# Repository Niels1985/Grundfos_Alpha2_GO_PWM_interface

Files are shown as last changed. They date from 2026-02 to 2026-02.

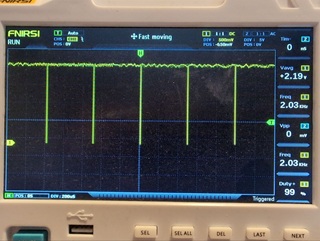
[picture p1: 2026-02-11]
foto2.jpg

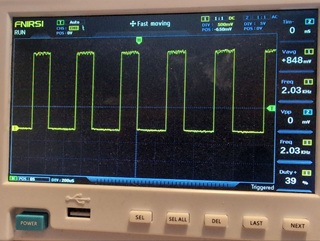
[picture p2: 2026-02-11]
foto1.jpg

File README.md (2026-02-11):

# Grundfos_Alpha2_GO_PWM_interface
Arduino IDE sketch for ATtiny85 microcontroller. When pin 7 (PB2) is high a PWM from 11% tot 84% is on pin 6 (PB1). Pin 3 (PB4) is analog in for potentiometer to set the PWM from 11% to 84%. When digital in is off then 97% PWM is send. (97% = pump off)(11% to 84% = pump minimum rpm to pum maximum rpm).

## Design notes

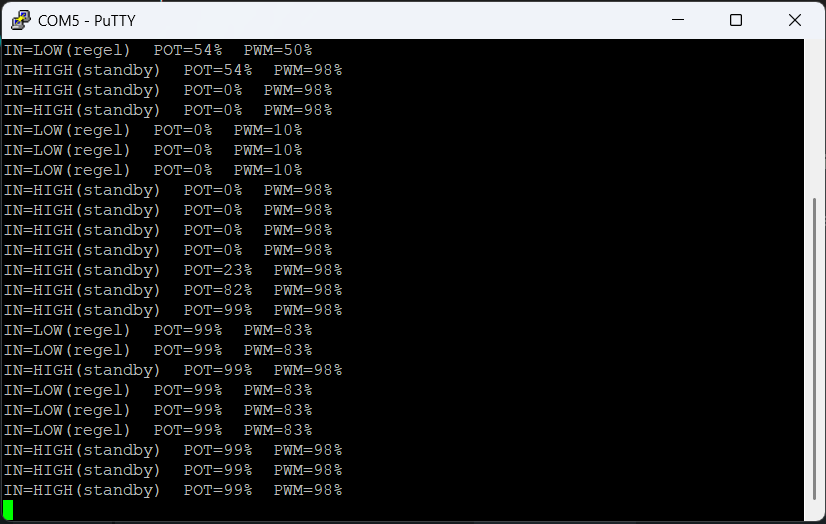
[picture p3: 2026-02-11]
serial_monitor.png

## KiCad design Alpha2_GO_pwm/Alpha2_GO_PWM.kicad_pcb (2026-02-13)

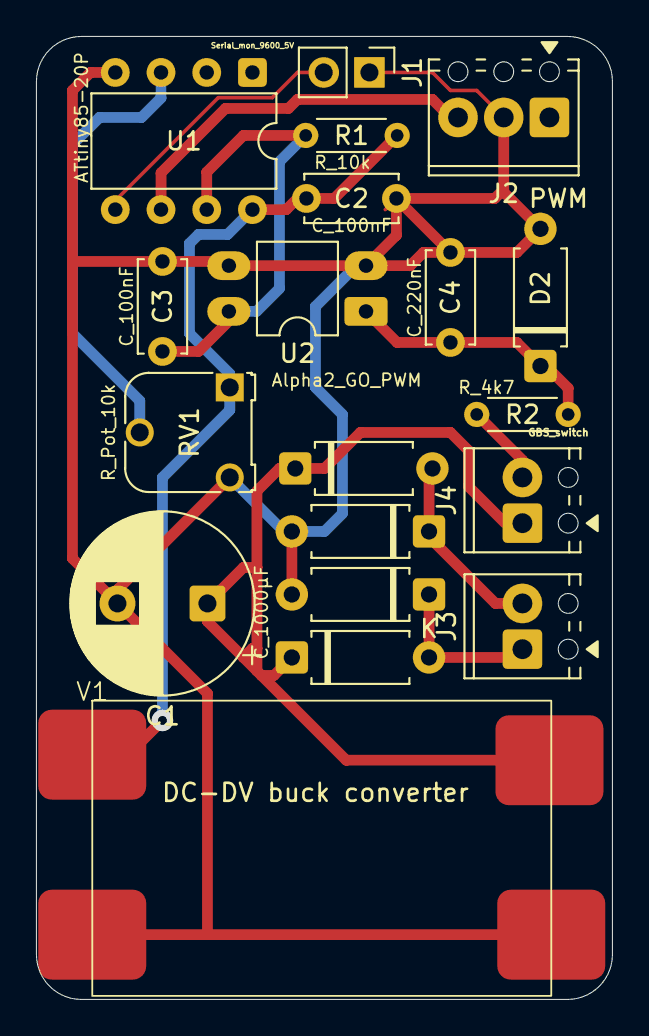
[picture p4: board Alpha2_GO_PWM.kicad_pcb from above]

Board: 2 copper layers, 32.0 x 53.5 mm, 19 parts (0 on the bottom side), 11 nets.

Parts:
C1: C_1000µF; CP_Radial_D10.0mm_P5.00mm
C2, C3: C_100nF; C_Disc_D5.0mm_W2.5mm_P5.00mm
C4: C_220nF; C_Disc_D5.0mm_W2.5mm_P5.00mm
D2: D_1N4148; D_A-405_P7.62mm_Horizontal
D3, D4, D5, D6: D; D_A-405_P7.62mm_Horizontal
J1: Serial_mon_9600_5V; PinHeader_1x02_P2.54mm_Vertical
J2: PWM; TerminalBlock_Phoenix_MPT-0,5-3-2.54_1x03_P2.54mm_Horizontal
J3: Suply 24V~; TerminalBlock_Phoenix_MPT-0,5-2-2.54_1x02_P2.54mm_Horizontal
J4: GBS_switch; TerminalBlock_Phoenix_MPT-0,5-2-2.54_1x02_P2.54mm_Horizontal
R1: R_10k; R_Axial_DIN0204_L3.6mm_D1.6mm_P5.08mm_Horizontal
R2: R_4k7; R_Axial_DIN0204_L3.6mm_D1.6mm_P5.08mm_Horizontal
RV1: R_Pot_10k; Potentiometer_Runtron_RM-065_Vertical
U1: ATtiny85-20P; DIP-8_W7.62mm
U2: Optocoupler_DC_PhotoNPN_AKEC; DIP-4_W7.62mm_LongPads
V1: V100EY9

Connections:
+5V: C2.2, R1.1, RV1.1, U1.8 (VCC), V1.4 (Vout-)
+24V: C1.1, D3.1 (K), D4.1 (K), J4.1, V1.1 (Vin+)
GND: C1.2, C2.1, C3.1, C4.1, D2.2 (A), D5.2 (A), D6.2 (A), J1.1, J2.2, RV1.3, U1.4 (GND), U2.2, U2.3, V1.2 (Vin-), V1.3 (Vout+)
unnamed: C4.2, D2.1 (K), R2.2, U2.1
unnamed: D3.2 (A), D5.1 (K), J3.2
unnamed: D4.2 (A), D6.1 (K), J3.1
unnamed: J1.2, U1.5 (AREF/PB0)
unnamed: J2.3, U1.6 (PB1)
unnamed: J4.2, R2.1
unnamed: C3.2, R1.2, U1.7 (PB2), U2.4
unnamed: RV1.2, U1.3 (XTAL2/PB4)

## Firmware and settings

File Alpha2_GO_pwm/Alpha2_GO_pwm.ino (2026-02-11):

// Niels Derksen 2026
// DEBUG info: PIN5 = (tegenover bolletje) Serieel TTL UART uit 9600 boud.
// Gebruik een TTL UART adapter op 5V voor uitlezing.
// Uit te lezen: Stand potmeter, PWM uitsturing, status digitaal in.


#include <Arduino.h>
#include <SoftwareSerial.h>

// ===== Pin mapping (ATtiny85 DIP-8) =====
// 1 = PB5/RESET  (niet gebruiken)
// 2 = PB3/ADC3   (vrij)
// 3 = PB4/ADC2   -> Potmeter wiper (ANALOG IN)
// 4 = GND
// 5 = PB0        -> Debug TX (SoftwareSerial TX-only)
// 6 = PB1/OC1A   -> PWM OUT naar pomp IN
// 7 = PB2        -> Digitale ingang (INPUT_PULLUP)
// 8 = VCC 5V

const uint8_t PIN_POT         = A2; // PB4, fysiek pin 3
const uint8_t PIN_PWM_OUT     = 1;  // PB1/OC1A, fysiek pin 6
const uint8_t PIN_DIGITAL_IN  = 2;  // PB2, fysiek pin 7
const uint8_t PIN_DBG_TX      = 0;  // PB0, fysiek pin 5

// Grundfos profiel A:
// 10..84% regelen, 95..100% standby/stop -> wij kiezen 98%
static const uint8_t DUTY_STANDBY = 98;
static const uint8_t DUTY_MIN     = 10;
static const uint8_t DUTY_MAX     = 84;

// 8 MHz -> 1 kHz: 8e6 / (64*(124+1)) = 1000 Hz
static const uint8_t TOP = 124;

// SoftwareSerial: RX pin is "dummy" (we gebruiken alleen TX)
SoftwareSerial dbg(255, PIN_DBG_TX); // RX=255 (niet gebruikt), TX=PB0

static inline uint8_t clamp_u8(int v, int lo, int hi) {
  if (v < lo) return (uint8_t)lo;
  if (v > hi) return (uint8_t)hi;
  return (uint8_t)v;
}

static void pwm_init_1kHz_OC1A() {
  pinMode(PIN_PWM_OUT, OUTPUT);

  TCCR1 = 0;
  GTCCR = 0;

  OCR1C = TOP;   // TOP bepaalt frequentie
  OCR1A = 0;     // duty

  // PWM op OC1A + prescaler /64
  TCCR1 = (1 << PWM1A) | (1 << COM1A1) | (1 << CS12) | (1 << CS11);
}

static void pwm_set_duty_percent(uint8_t dutyPercent) {
  dutyPercent = clamp_u8(dutyPercent, 0, 100);

  uint16_t ocr = (uint16_t)((uint32_t)dutyPercent * (uint32_t)(TOP + 1) + 50) / 100;
  if (ocr > TOP) ocr = TOP;
  OCR1A = (uint8_t)ocr;
}

static uint16_t read_pot_filtered() {
  uint32_t sum = 0;
  for (uint8_t i = 0; i < 8; i++) {
    sum += (uint16_t)analogRead(PIN_POT);
    delay(2);
  }
  return (uint16_t)(sum / 8);
}

void setup() {
  pinMode(PIN_DIGITAL_IN, INPUT_PULLUP); // los = HIGH, naar GND = LOW (actief)
  analogReference(DEFAULT);

  pwm_init_1kHz_OC1A();
  pwm_set_duty_percent(DUTY_STANDBY); // veilig starten: standby/stop

  dbg.begin(9600);
  dbg.println(F("ATtiny85 Alpha2GO PWM start"));
}

void loop() {
  // Inverted logic:
  // LOW (naar GND)  => regelmodus
  // HIGH (los)      => standby/stop
  const bool regelmodus = (digitalRead(PIN_DIGITAL_IN) == LOW);

  uint16_t adc = read_pot_filtered();           // 0..1023
  uint8_t potPercent = (uint8_t)((uint32_t)adc * 100UL / 1023UL);

  uint8_t dutyOut;

  if (!regelmodus) {
    dutyOut = DUTY_STANDBY;
  } else {
    int duty = DUTY_MIN + (int)((uint32_t)adc * (DUTY_MAX - DUTY_MIN) / 1023UL);
    dutyOut = clamp_u8(duty, DUTY_MIN, DUTY_MAX);
  }

  pwm_set_duty_percent(dutyOut);

  // Debug elke 3 seconden
  static uint32_t tLast = 0;
  uint32_t now = millis();
  if (now - tLast >= 3000UL) {
    tLast = now;

    dbg.print(F("IN="));
    dbg.print(regelmodus ? F("LOW(regel)") : F("HIGH(standby)"));

    dbg.print(F("  POT="));
    dbg.print(potPercent);
    dbg.print(F("%"));

    dbg.print(F("  PWM="));
    dbg.print(dutyOut);
    dbg.println(F("%"));
  }

  delay(20);
}
